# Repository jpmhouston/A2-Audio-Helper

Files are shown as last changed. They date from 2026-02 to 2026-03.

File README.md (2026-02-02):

This is a potential Apple II hardware mod I hope to eventually turn into a working physical add-on for any ][, ][+, //e. It’s meant to add these capabilities:

- route sound card audio to the stock speaker
- mixing motherboard audio into the sound card audio (i believe some sound cards don’t come with this feature)
- an optional second speaker mounted into the case for stereo (mounting strategy not determined yet)
- control volume with a knob protruding through a hole dremel'd into case beneath the keyboard (willing to accept feedback about an alternate volume control and placement, of if volume control should be made optional)
- when volume knob turned off, output to a line-out jack at the back of the case (attached to one of those mounts for a //e, not sure what yet for older ][’s)
- output to headphone jack at the back of the case, also controlled by the volume knob, disabling the speaker(s) when connected (also attached to one of those mounts for a //e, maybe both jacks out one wide slot)
- optionally output to another headphone jack at the front of the case (via a second hole in the case beside the volume knob)

These features should be possible using a small circuit board to be mounted within the case beneath the keyboard with some minor modifications, either one or two holes drilled into the case's metal base, the part that's angled upwards. It should require no controller or firmware, and the plan is to connect it to power and ground via the motherboard’s game port (potentially using a pass-through socket to permit its use for joysticks or whatever else). 

The schematic originates from a specification fed to Gemini and a KiCad project created according to its design, making use of a 8403 amplifier module. Needless to say there were numerous back and forth sessions. I created a simple PCB design as a proof of concept, currently all through-hole components. Well it leverages a ready-to-use amplifier module with its own surface-mount components, but that itself needs connection with pin headers.

The latest iteration of the PCB is 4.5cm wide and 6.3cn tall, and I'm hoping they will fit, on a //e between the motherboard and the end of the flat part of the base, somewhat in the center or right of the case. On a ][ / ][+ I'm hoping there's room in front of the power supply. I know the stock speaker is in that area, I'll have to see more 2's in the wild and see. For both models there should also be space at the far right side of the vents for an second speaker to be mounted somehow.

Volume and front headphone are on a small daughterboard, connected via a ribbon cable, that can mount flush to the upwardly angled part of the base, I'm hoping there's room directly under the keyboard at this angle and still allow the knob and jack to be high enough off the table to be useful. The main board however is also able to have the volume and headphone jack populated on it directly instead, for those wanting to mount it with those controls protruding out the side of the case. I'm making it support this just for me really, as my own case if damaged and I don't mind making holes in the beige plastic, and especially if I run into space issues under the keybaord. I suspect this option will be less of an interest to others since making holes in the beige plastic is not something they'd want to do, and not something I'd recommend.

I also am planning how to mount line-out and optionally a second headphone jack to the back of the case. I've found what might be good jack components, and I think they'll work in one of the long //e openings, but not sure yet. I suspect some 3D-printed thing will be involved in making this work.

I'm putting the cart before the horse a bit iterating over the PCB layout and pondering these physical issues, as I’ve still yet to test an implementation of the schematic on a breadboard.

Feedback and assistance are appreciated on the Discussions page for this repo, especially feedback on the schematic and PCB since I really a beginner in all this. Especially feedback on the physical mounting and modding challenges for this thing. Thanks.

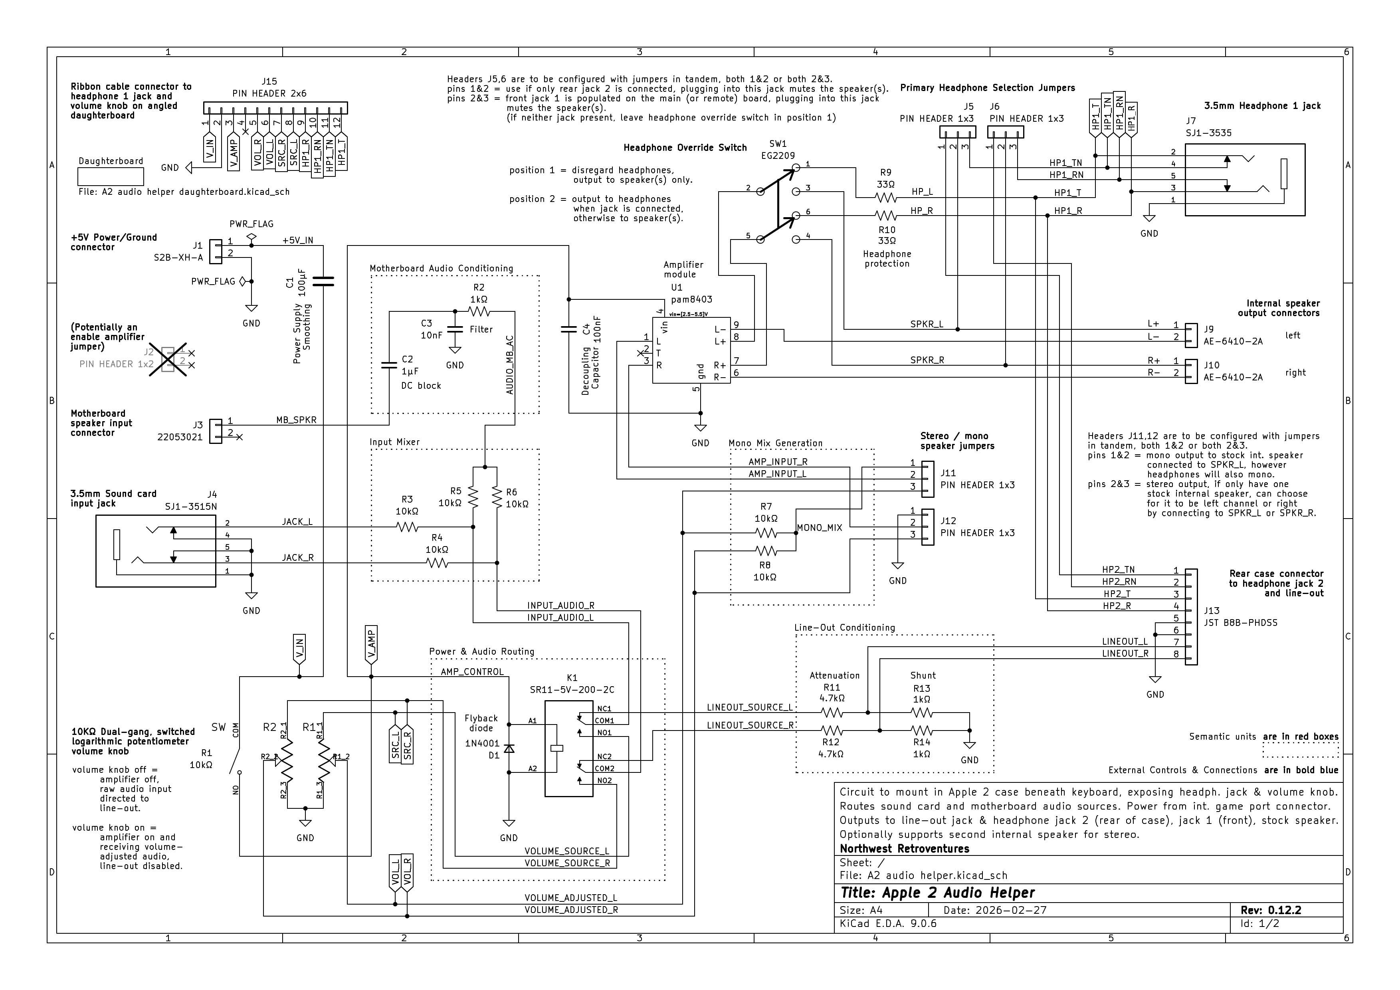
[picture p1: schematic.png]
schematic


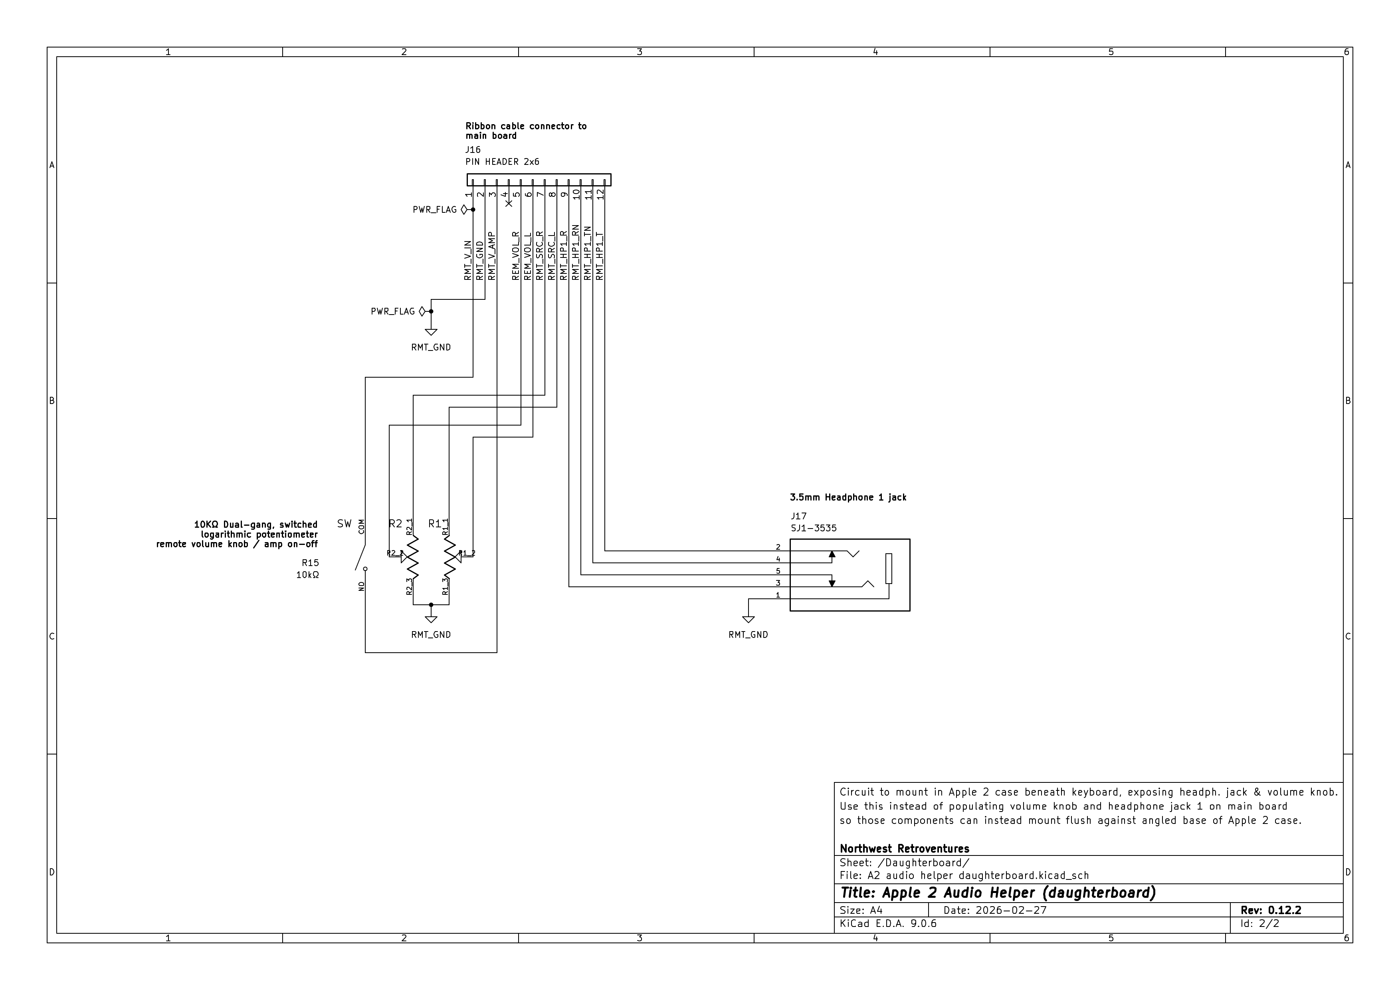
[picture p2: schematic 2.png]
schematic


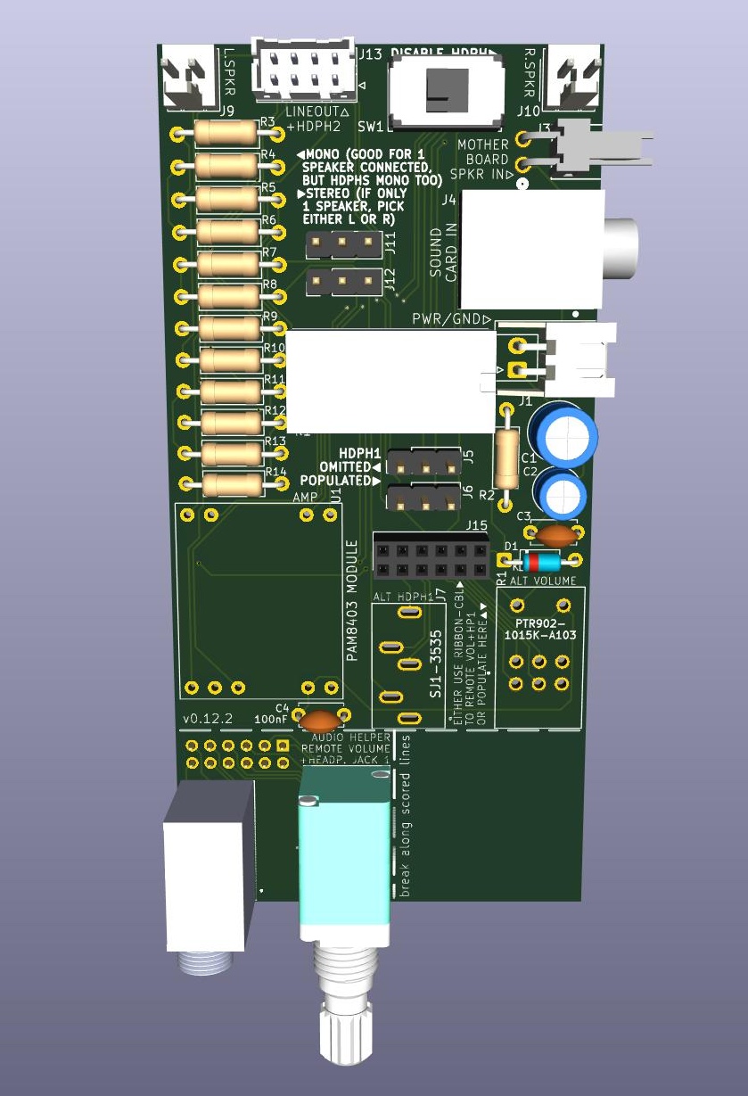
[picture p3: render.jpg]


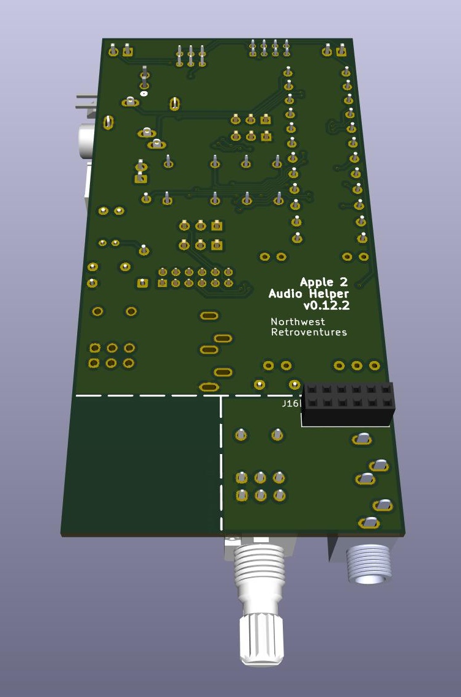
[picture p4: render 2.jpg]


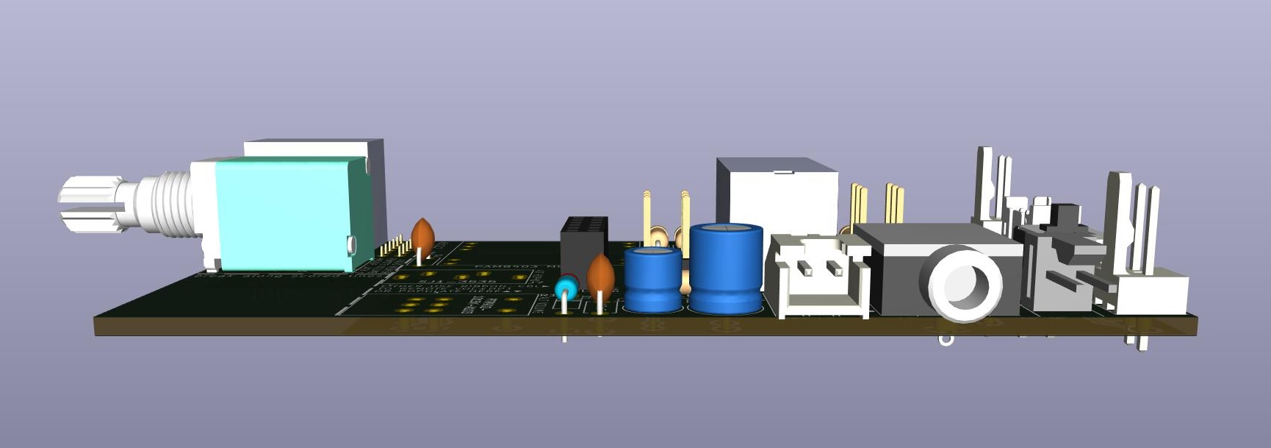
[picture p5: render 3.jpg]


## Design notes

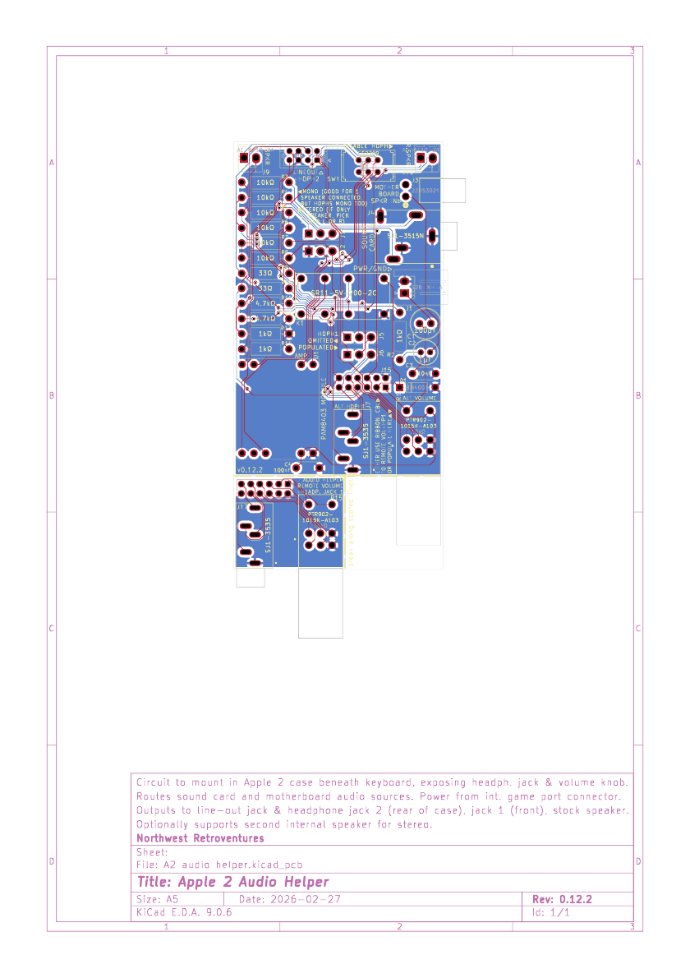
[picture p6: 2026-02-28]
pcb.png

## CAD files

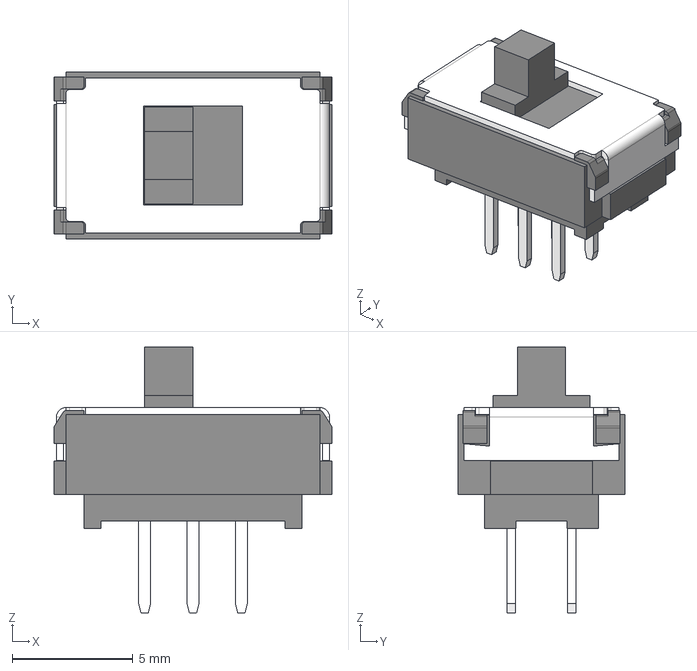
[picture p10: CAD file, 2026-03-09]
EG2209/EG2209.step
11.5 x 6.90 x 11.0 mm

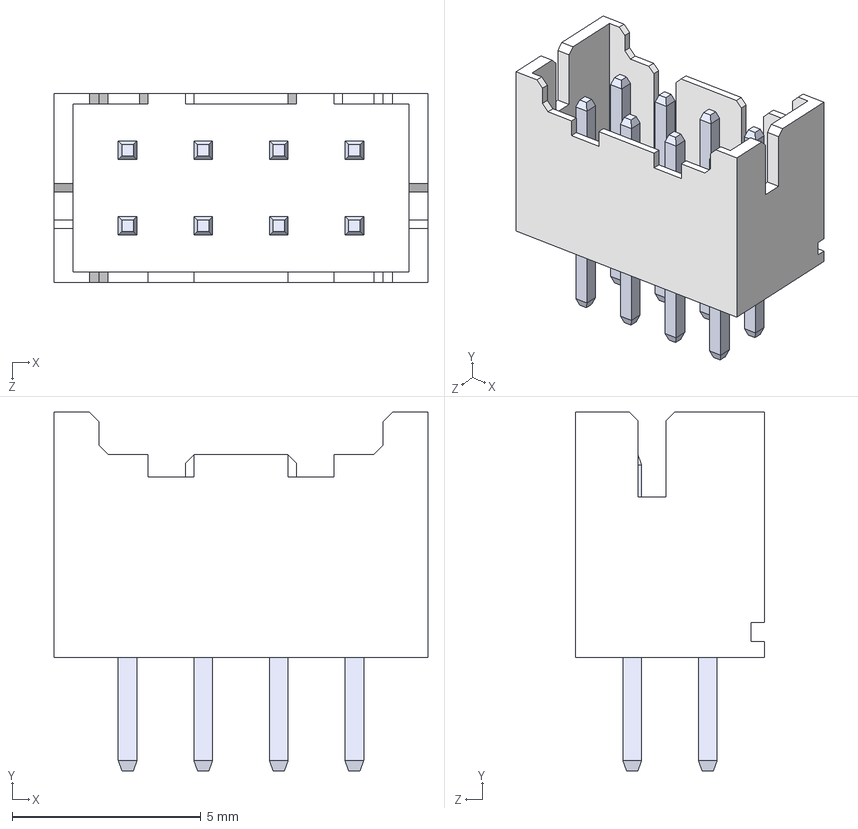
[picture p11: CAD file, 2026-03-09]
JST B8B-PHDSS/B8B-PHDSS -LF--SN---3DModel-STEP-56544.STEP
9.90 x 9.50 x 5.00 mm
BxB-PHDSS_8
pin^BxB-PHDSS ass x 8

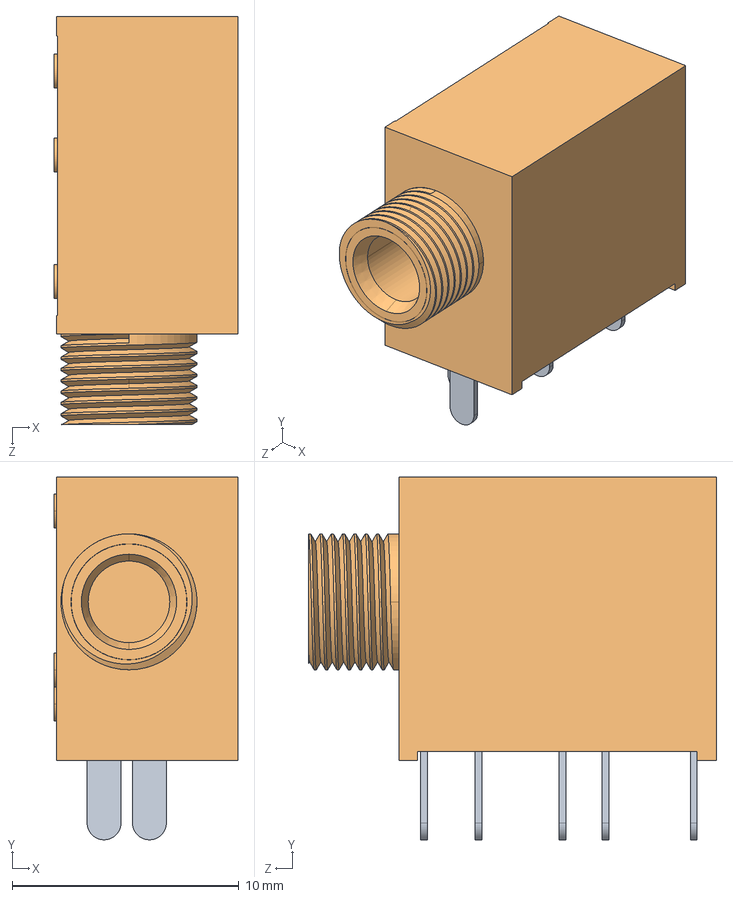
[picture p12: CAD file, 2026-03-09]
SJ1-3535/SJ1-3535.step
8.10 x 16.0 x 18.0 mm

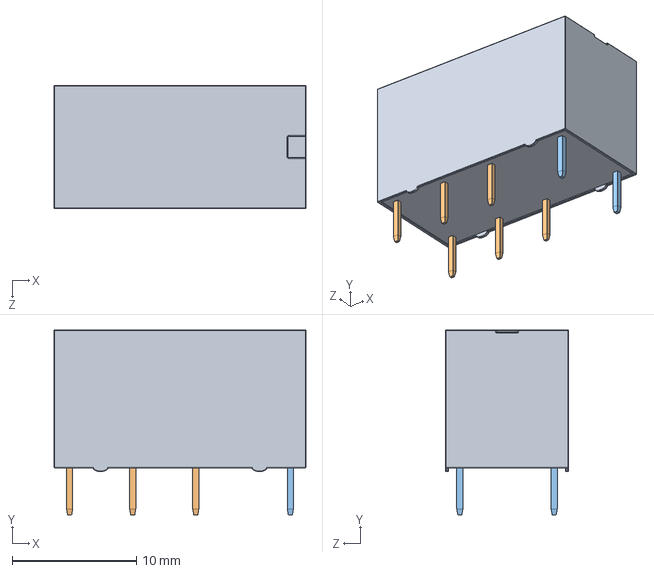
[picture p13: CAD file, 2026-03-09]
SR11-5V-200-2C/SR11-5V-200-2C.step
20.3 x 14.9 x 9.90 mm

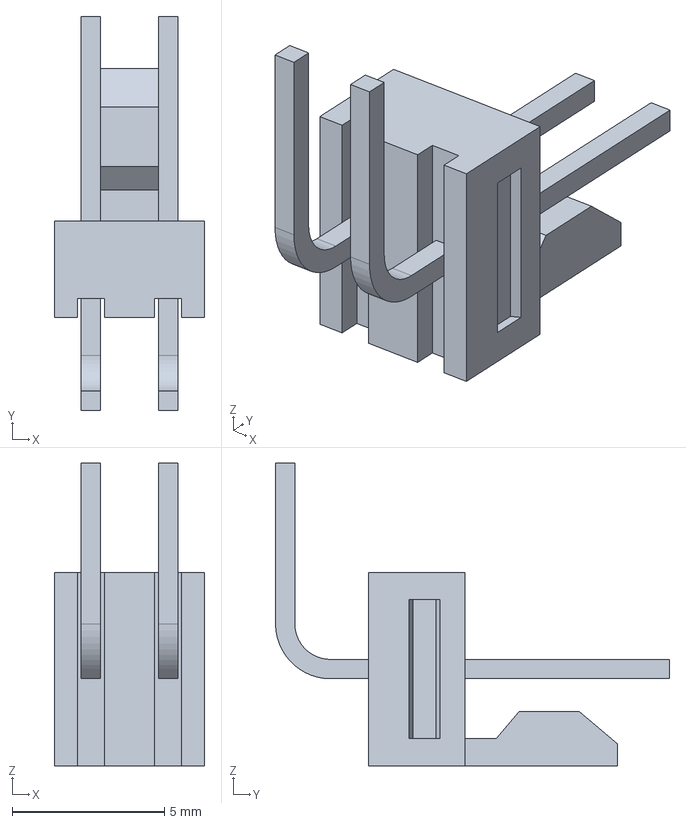
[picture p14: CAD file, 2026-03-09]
Molex 22053021/178334604-659-0022053021/0022053021.stp
4.93 x 12.9 x 9.93 mm

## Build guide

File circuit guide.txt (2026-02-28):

Revision 12 Circuit Design (New headphone 1 jack, switch, layout, remove rev11 experiment)

Libraries, STEP AP242 3D Models for KiCad (add manually, project specific):
* https://github.com/johnnycubides/pam8403-module-kicad-lib (downloaded git repo)
* https://www.snapeda.com/parts/PTR902-1020K-A502/Bourns/view-part/ (symbol file)
* https://www.digikey.com/en/models/24767735 (footprint, 3d model files PTN09S2-H10215K1A analogue to PTR902)
* https://www.snapeda.com/parts/SR11-5V-200-2C/Same%20Sky/view-part/ (symbol, footprint, 3d model files)
* https://www.snapeda.com/parts/SJ1-3515N/Same%20Sky/view-part/ (symbol, footprint, 3d model files)
* https://www.snapeda.com/parts/SJ1-3535/Same%20Sky/view-part/ (symbol, footprint, 3d model files)
* https://www.snapeda.com/parts/EG2209/E-Switch/view-part/ (symbol, footprint, 3d model files)
* https://www.snapeda.com/parts/22053021/Molex/view-part (footprint, 3d model into "Molex 22053021" dir)
* https://www.snapeda.com/parts/B8B-PHDSS%20%28LF%29%28SN%29/JST/view-part/ (3d model into "JST B8B-PHDSS" dir)

--

Component List (Reference Designators)

Main Board

* U1 / U_AMP: PAM8403 Module (Amplifier Module)
* R1 / R_VOL | R_VOL_L, R_VOL_R, SW_R_VOL: 10KΩ Switched Dual-Gang Logarithmic Potentiometer (Volume Knob)
  https://www.snapeda.com/parts/PTR902-1015K-A103/Bourns/view-part/
  footprint PTR902-1020K-A502
  3d model PTR902-1020K-A502/ptr901-2x15k-xxxx.stp
* SW1 / SW_HP_OVERRIDE: DPDT Switch (Headphone Override)
  https://www.snapeda.com/parts/EG2209/E-Switch/view-part/
  footprint EG2209:EG2209
* K1 / RL_AUDIO_RELAY: Relay_DPDT symbol (Mode Relay Routing Audio to Amplifier or Line-Out)
  https://leeselectronic.com/en/product/3219-relayhkehrs2-5vdc-coildpdt1a.html
  https://www.snapeda.com/parts/SR11-5V-200-2C/Same%20Sky/view-part/
  footprint SR11-5V-200-2C:RELAY_SR11-5V-200-2C
  3d model SR11-5V-200-2C/SR11-5V-200-2C.step

* J1 / J_PWR: Conn_01x02 symbol (Main Power Input)
  JST-XH connector more standard than the molex I picked out of a hat, good footprint & model present in kicad
  https://www.snapeda.com/parts/S2B-XH-A/JST%20Sales/view-part
  footprint Connector_JST:JST_XH_S2B-XH-A_1x02_P2.50mm_Horizontal
* J2 / JP_EN_AMP: Conn_01x02 symbol (Jumper to Enable +5V power to U_AMP, omitted from pcb currently)
  footprint PinHeader_1x02_P2.54mm_Vertical
* J3 / J_SPKR_IN: Conn_01x02 symbol (Motherboard Audio Input)
  https://www.snapeda.com/parts/22053021/Molex/view-part/
  footprint Molex 22053021:CONN_A-7478-02A_MOL
  3d model Molex 22053021/178333781-659-0022053021/0022053021.stp
* J4 / J_SCARD_IN: AudioJack3_Ground_Switch symbol (Switching Sound Card Input Jack)
  https://leeselectronic.com/en/product/160956-35mm-stereo-jack-breadboard-friendly.html get this for testing
  https://www.snapeda.com/parts/SJ1-3515N/Same%20Sky/view-part/
  footprint SJ1-3515N:CUI_SJ1-3515N
  3d model SJ1-3515N/SJ1-3515N.step
* J5,6 / JP_SW_PRIM_HP_L, JP_SW_PRIM_HP_R: Two Conn_01x03 symbols (Jumpers for Which Headphone Jack Mutes Speakers)
  footprint PinHeader_1x03_P2.54mm_Vertical
* J7 / J_HP1_OUT: AudioJack3_Ground_Switch symbol (Switching Headphone 1 Jack)
  https://www.snapeda.com/parts/SJ1-3535/Same%20Sky/view-part/
  footprint SJ1-3535:CUI_SJ1-3535
* J8 now unused, was separate connector to hp1 jack
* J9,10 / J_SPKR_OUT_L, J_SPKR_OUT_L: Conn_01x02 symbol (Speaker Output)
  https://www.snapeda.com/parts/22272021/Molex/view-part/
  https://www.molex.com/en-us/products/part-detail/22272021
  footprint Connector_Molex:Molex_KK-254_AE-6410-02A_1x02_P2.54mm_Vertical
* J11,12 / JP_EN_RSPKR_L, JP_EN_RSPKR_R: Two Conn_01x03 symbols (Jumpers for Mono/Stereo Speaker Mode)
  footprint PinHeader_1x03_P2.54mm_Vertical
* J13 / J_REAR_CONN: Conn_01x07 symbol (Connector to Switching Headphone 2 Jack and Line-Out)
  pins are numbered from 1 to 7: HP2_T, HP2_TN, HP2_R, HP2_RN, LINEOUT_L, LINEOUT_R, GND
  JST PHD series, 2.0mm, B8B-PHDSS
  https://www.snapeda.com/parts/B8B-PHDSS(LF)(SN)/JST%20Sales/view-part/
  footprint Connector_JST:JST_PHD_B8B-PHDSS_2x04_P2.00mm_Vertical
  3d model JST B8B-PHDSS/B8B-PHDSS -LF--SN---3DModel-STEP-56544.STEP
* J14 now unused, was separate connector to line-out
* J15 / J_TORMT_RBNCONN: Conn_02x06 symbol (Ribbon cable connector to remote J_RMT_HP1_OUT + R_RMT_VOL)
  footprint Connector_PinSocket_2.00mm:PinSocket_2x06_P2.00mm_Vertical
  https://www.snapeda.com/parts/M22-7140642/Harwin/view-part/
  https://www.snapeda.com/parts/SMM-106-01-S-D/Samtec/view-part/
  2" cable https://www.snapeda.com/parts/TCMD-06-D-02.00-01/Samtec/view-part/

* D1 / D_RELAY_FLYBACK: 1N4148 (or could use 1N4001/1N4007) Diode (Flyback Diode for Mode Relay)
  https://leeselectronic.com/en/product/7113-7113DIODEFASTSWITCHING1N41484PCS.html 
  https://www.snapeda.com/parts/JANTX1N4148-1/Microsemi%20Corporation/view-part/
  footprint Diode_THT:D_DO-35_SOD27_P7.62mm_Horizontal
* C1 / C_PWR_SMOOTH: 100µF Electrolytic Capacitor (Power Supply Smoothing)
  footprint C_Radial_D6.3mm_H7.0mm_P2.50mm
* C2 / C_MB_DC_BLOCK: 1µF Capacitor (Motherboard Audio DC Blocking)
  footprint C_Radial_D5.0mm_H5.0mm_P2.00mm
* C3 / C_MB_FILTER: 10nF Capacitor (Motherboard Audio Filtering)
  footprint C_Disc_D4.7mm_W2.5mm_P5.00mm
* C4 / C_AMP_DECOUPLING: 100nF Capacitor (Amp VCC Decoupling Capacitor)
  footprint Capacitor_THT:C_Disc_D4.7mm_W2.5mm_P5.00mm
* R2 / R_MB_FILTER: 1kΩ Resistor (Motherboard Audio Filtering)
* R3,4 / R_MIX_SCARD_L, R_MIX_SCARD_R: 10kΩ Resistors (Input Mixer for Sound Card Audio)
* R5,6 / R_MIX_MB_L, R_MIX_MB_R: 10kΩ Resistors (Input Mixer for Motherboard Audio)
* R7,8 / R_MONO_MIX_L, R_MONO_MIX_R: 10kΩ Resistors (Output Mono Mix for speakers)
* R9,10 / R_HP_PROT_L, R_HP_PROT_R: 33Ω Resistors (Headphone Protection)
* R11,12 / R_LINE_ATTEN_L, R_LINE_ATTEN_R: 4.7kΩ Resistors (Line-out Attenuation, Series)
* R13,14 / R_SHUNT_L, R_SHUNT_R: 1kΩ Resistors (Line-out Attenuation, Shunt)
  footprint for all restistors R_Axial_DIN0207_L6.3mm_D2.5mm_P10.16mm_Horizontal

Daughterboard

* J16 / J_RMT_RBNCONN: Conn_02x06 symbol (Ribbon cable connector to/at remote J_HP1_OUT + R_VOL)
  footprint Connector_PinSocket_2.00mm:PinSocket_2x06_P2.00mm_Vertical
  https://www.snapeda.com/parts/M22-7140642/Harwin/view-part/
  https://www.snapeda.com/parts/SMM-106-01-S-D/Samtec/view-part/
  2" cable https://www.snapeda.com/parts/TCMD-06-D-02.00-01/Samtec/view-part/
* J17 / J_RMT_HP1_OUT: AudioJack3_Ground_Switch symbol (Switching Headphone 1 Jack)
  https://www.snapeda.com/parts/SJ1-3535/Same%20Sky/view-part/
  footprint SJ1-3535:CUI_SJ1-3535
* R15 / R_RMT_VOL: 10KΩ Switched Dual-Gang Logarithmic Potentiometer (Volume Knob)
  https://www.snapeda.com/parts/PTR902-1015K-A103/Bourns/view-part/
  (model files from the similar 5KΩ part www.snapeda.com/parts/PTR902-1020K-A502/Bourns/view-part/)
  footprint PTR902-1020K-A502
  3d model PTR902-1020K-A502/ptr901-2x15k-xxxx.stp

Also (not on any board or schematic)

* J17 / J_LINEOUT (Rear Case Line-Out Jack)
  Samesky SJ3-35053D 3.5 mm Stereo Jack, Through Hole, 3 Conductors, 2 Internal Switches 
  https://www.sameskydevices.com/product/interconnect/connectors/audio-connectors/jacks/sj3-35053d
* J18 / J_HP2 (Rear Case Headphone 2 Jack)
  Samesky SJ3-35053A 3.5 mm Stereo Jack, Through Hole, 3 Conductors, 0 Internal Switches 
  https://www.sameskydevices.com/product/interconnect/connectors/audio-connectors/jacks/sj3-35053a

Centers of headphone 1 jack and volume knob are 15mm apart, very close to 19/32", ie. 5/8" minus 1/32"
(requires a 0.5mm spacer between board and knob R_VOL)
Holes ~6mm diam. (jack's screw is M6 ie. outer diam. 5.8mm, however knob suggest 6mm is its screw's inner diam)

---

Schematic Description

Block 1: Main Power Input & Amplifier Power Control
* J_PWR (Main Power Header):
    * Pin 1 provides the +5V_IN net.
    * Pin 2 provides the GND net.
* C_PWR_SMOOTH (Power Smoothing Capacitor):
    * Connect the positive lead of C_PWR_SMOOTH to +5V_IN.
    * Connect the negative lead of C_PWR_SMOOTH to GND.
    * Effect: This capacitor acts as a local power reservoir to filter noise and smooth out voltage drops from the Apple II's power supply.
* JP_EN_AMP (Amplifier Enable Jumper):
    * Pin 1 connects to +5V_IN.
    * Pin 2 provides the V_IN_ENABLED net.
    * Effect: When a jumper shunt is present, power is passed to the rest of the circuit.

Block 2: Input Stage & Pre-Mixer
* J_SPKR_IN (Motherboard Audio Header):
    * Pin 1 (MB_SPKR): Connect to C_MB_DC_BLOCK, plug connects to Apple II Speaker Switched Output signal, J18 pin 1 (precise pin needs to be verified).
    * Pin 2: No connection (plug must not connect to J18 pin 2!).
* JP_EN_SPKR_IN (Jumper to Enable MB Audio, currenly omitted but was in between MB_SPKR pin 1 and C_MB_DC_BLOCK):
    * Now unused, but was:
        * Pin 1: Connect to the MB_SPKR signal from J_SPKR_IN.
        * Pin 2: Connect to the MB_SPKR_ENABLED net (ie. to C_MB_DC_BLOCK).
        * Effect: Placing a jumper shunt on JP_EN_SPKR_IN enables the motherboard audio. Removing it disables it.
* Motherboard Audio Conditioning:
    * The MB_SPKR signal goes through series C_MB_DC_BLOCK.
    * Then, it goes through series R_MB_FILTER.
    * A C_MB_FILTER capacitor connects from after R_MB_FILTER to GND. This creates the AUDIO_MB_AC net.
* J_SCARD_IN (Switching Line-In Jack):
    * Tip pin provides the JACK_L net.
    * Ring pin provides the JACK_R net.
    * Sleeve pin connects to GND.
    * The Tip_NC and Ring_NC (Normally Closed) pins connect to GND for noise prevention when no plug is inserted.

Block 3: Mixer
* Input Mixer:
    * AUDIO_MB_AC -> R_MIX_MB_L -> INPUT_AUDIO_L net.
    * AUDIO_MB_AC -> R_MIX_MB_R -> INPUT_AUDIO_R net.
    * JACK_L -> R_MIX_SCARD_L -> INPUT_AUDIO_L net.
    * JACK_R -> R_MIX_SCARD_R -> INPUT_AUDIO_R net.
* Effect: The INPUT_AUDIO_L/R nets now contain a mix of the conditioned motherboard audio (if JP_EN_SPKR_IN is installed) and the line-in signal (if present in J_SCARD_IN).

Block 4: Line-Out / Amp Mode Selection (Volume Knob Switch) & Volume Control
* SW_R_VOL (SPST Switch on R_VOL):
    * Conect one terminal to V_IN_ENABLED.
    * Connect the other terminal to the AMP_CONTROL_SIGNAL net.
* D_RELAY_FLYBACK (Flyback Diode):
    * Cathode (banded end): Connect to AMP_CONTROL_SIGNAL.
    * Anode (non-banded end): Connect to GND.
* RL_AUDIO_RELAY (DPDT Relay) Coil Connections:
    * One side of the relay coil (e.g., A1): Connect to AMP_CONTROL_SIGNAL.
    * The other side of the relay coil (e.g., A2): Connect to GND.
* RL_AUDIO_RELAY (DPDT Relay) Audio Contact Connections:
    * Pole A (Left Channel):
        * Common pin: Connect to INPUT_AUDIO_L.
        * Normally Closed (NC) pin: Connect to LINEOUT_SOURCE_L.
        * Normally Open (NO) pin: Connect to VOLUME_SOURCE_L.
    * Pole B (Right Channel):
        * Common pin: Connect to INPUT_AUDIO_R.
        * Normally Closed (NC) pin: Connect to LINEOUT_SOURCE_R.
        * Normally Open (NO) pin: Connect to VOLUME_SOURCE_R.
* R_VOL_L (Left Gang on R_VOL):
    * Pin 1 (End of Track): Connects to VOLUME_SOURCE_L.
    * Pin 2 (Wiper): Provides the VOLUME_ADJUSTED_L net.
    * Pin 3 (Other End of Track): Connects to GND.
* R_VOL_R (Right Gang on R_VOL):
    * Pin 4 (End of Track): Connects to VOLUME_SOURCE_R.
    * Pin 5 (Wiper): Provides the VOLUME_ADJUSTED_R net.
    * Pin 6 (Other End of Track): Connects to GND.
* Effect:
    * When SW_R_VOL is OFF:
        * The AMP_CONTROL_SIGNAL net and U_AMP are disconnected from V_IN_ENABLED.
        * Audio is routed to LINEOUT_SOURCE_L/R.
    * When SW_R_VOL is ON:
        * The AMP_CONTROL_SIGNAL net and U_AMP are connected to V_IN_ENABLED.
        * Audio is routed to VOLUME_SOURCE_L/R for amplification.

Block 5: Mono Mix Generation & Amplifier Input (Two-Jumper Version)
* Mono Mix Generation: A MONO_MIX_POINT net is created by mixing VOLUME_ADJUSTED_L and VOLUME_ADJUSTED_R through R_MONO_MIX_L and R_MONO_MIX_R.
* JP_EN_RSPKR_L (Left Channel Jumper):
    * Pin 1 (Stereo): Connect to VOLUME_ADJUSTED_L.
    * Pin 2 (Common): Connect to AMP_INPUT_L.
    * Pin 3 (Mono): Connect to MONO_MIX_POINT.
* JP_EN_RSPKR_R (Right Channel Jumper):
    * Pin 1 (Stereo): Connect to VOLUME_ADJUSTED_R.
    * Pin 2 (Common): Connect to AMP_INPUT_R.
    * Pin 3 (Mono): Connect to GND.

Block 6: Amplifier Module
* U_AMP (PAM8403 Module):
    * VCC pin: Connect to AMP_CONTROL_SIGNAL.
    * Ground pin: Connect to GND.
    * L and R input pins: Connect to AMP_INPUT_L and AMP_INPUT_R.
    * L+ and R+ output pins: Connect to the common pins of SW_HP_OVERRIDEA/B.
    * L- and R- output pins: Connect to pin 2 (L-) of J_SPKR_OUT_L and pin 2 (R-) of J_SPKR_OUT_R.

Block 7: Amplified Output Routing
* SW_HP_OVERRIDEA & SW_HP_OVERRIDEB (Headphone Override Switch):
    * The Common pin of SW_HP_OVERRIDEA: Connect to the L+ output of U_AMP.
    * The Common pin of SW_HP_OVERRIDEB: Connect to the R+ output of U_AMP.
    * Throw 2 ("Forced Speaker") of SW_HP_OVERRIDEA: Connect directly to pin 1 (L+) of J_SPKR_OUT_L.
    * Throw 2 ("Forced Speaker") of SW_HP_OVERRIDEB: Connect directly to pin 1 (R+) of J_SPKR_OUT_R.
    * Throw 1 ("Auto") of SW_HP_OVERRIDEA: Connect to the input of the R_HP_PROT_L resistor.
    * Throw 1 ("Auto") of SW_HP_OVERRIDEB: Connect to the input of the R_HP_PROT_R resistor.
* Parallel Audio Path to Headphone Jacks:
    * Output of R_HP_PROT_L: Connect to the HP_L net, connecting in parallel the T (Tip) pin of the J_HP1_OUT jack and pin 1 of J_REAR_CONN (to the T (Tip) pin of the HP2 jack).
    * Output of R_HP_PROT_R: Connect to the HP_R net, connecting in parallel the R (Ring) pin of the J_HP1_OUT jack and pin 3 of J_REAR_CONN (to the R (Ring) pin of the HP2 jack).
    * The signal goes in parallel to the 2 headphones, but when the jumper headers JP_SW_PRIM_HP_L, JP_SW_PRIM_HP_R have pins 1&2 bridged, this will indicate headphone 2 is primary. When pins 2&3 bridged this will indicate headphone 1 is primary. Primary means the headphone that controls muting the speaker(s).
* Headphone Routing:
    * The TN (Tip Normal) pin of J_HP1_OUT: Connect to pin 3 of JP_SW_PRIM_HP_L.
    * The RN (Ring Normal) pin of J_HP1_OUT: Connect to pin 3 of JP_SW_PRIM_HP_R.
    * The S (Sleeve) pin of J_HP1_OUT: Connect to GND.
    * Pin 2 of J_REAR_CONN (to the TN (Tip Normal) pin of the HP2 jack): Connect to pin 1 of JP_SW_PRIM_HP_L.
    * Pin 4 of J_REAR_CONN (to the RN (Ring Normal) pin of the HP2 jack): Connect to pin 1 of JP_SW_PRIM_HP_R.
    * Pin 7 of J_REAR_CONN (to the S (Sleeve) pin of the HP2 jack): Connect to GND.
    * Pin 2 of JP_SW_PRIM_HP_L: Connect to pin 1 (L+) of J_SPKR_OUT_L.
    * Pin 2 of JP_SW_PRIM_HP_R: Connect to pin 1 (R+) of J_SPKR_OUT_R.
* J_SPKR_OUT (Speaker Output Header):
    * L+/R+ pins: Fed by either pins 2 of JP_SW_PRIM_HP_L and JP_SW_PRIM_HP_R, OR from the "Forced Speaker" throws of SW_HP_OVERRIDEA/B.
    * L-/R- pins: Connect directly to the L-/R- outputs of U_AMP.

Block 8: Line-Out Jack
* Line-out signal connects to J_REAR_CONN:
    * LINEOUT_SOURCE_L -> R_LINE_ATTEN_L -> pin 5 of J_REAR_CONN.
    * LINEOUT_SOURCE_R -> R_LINE_ATTEN_R -> pin 6 of J_REAR_CONN.
    * Connect a shunt resistor (R_SHUNT_L/R_SHUNT_R) from each output pin to GND to form the voltage divider.

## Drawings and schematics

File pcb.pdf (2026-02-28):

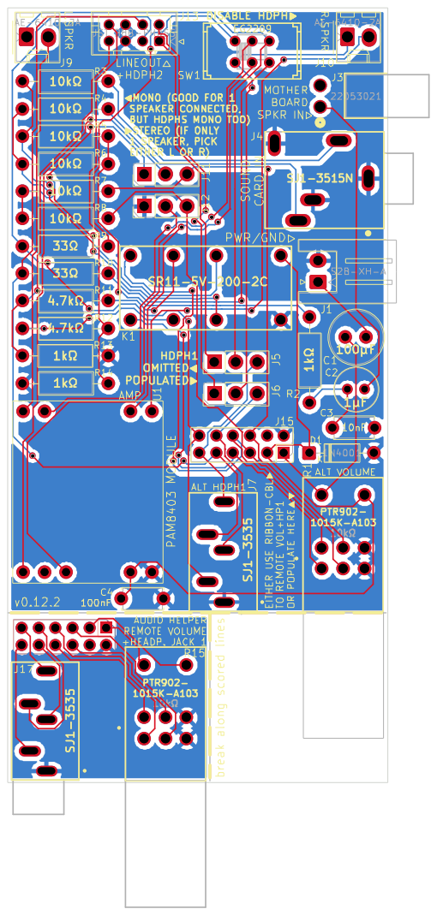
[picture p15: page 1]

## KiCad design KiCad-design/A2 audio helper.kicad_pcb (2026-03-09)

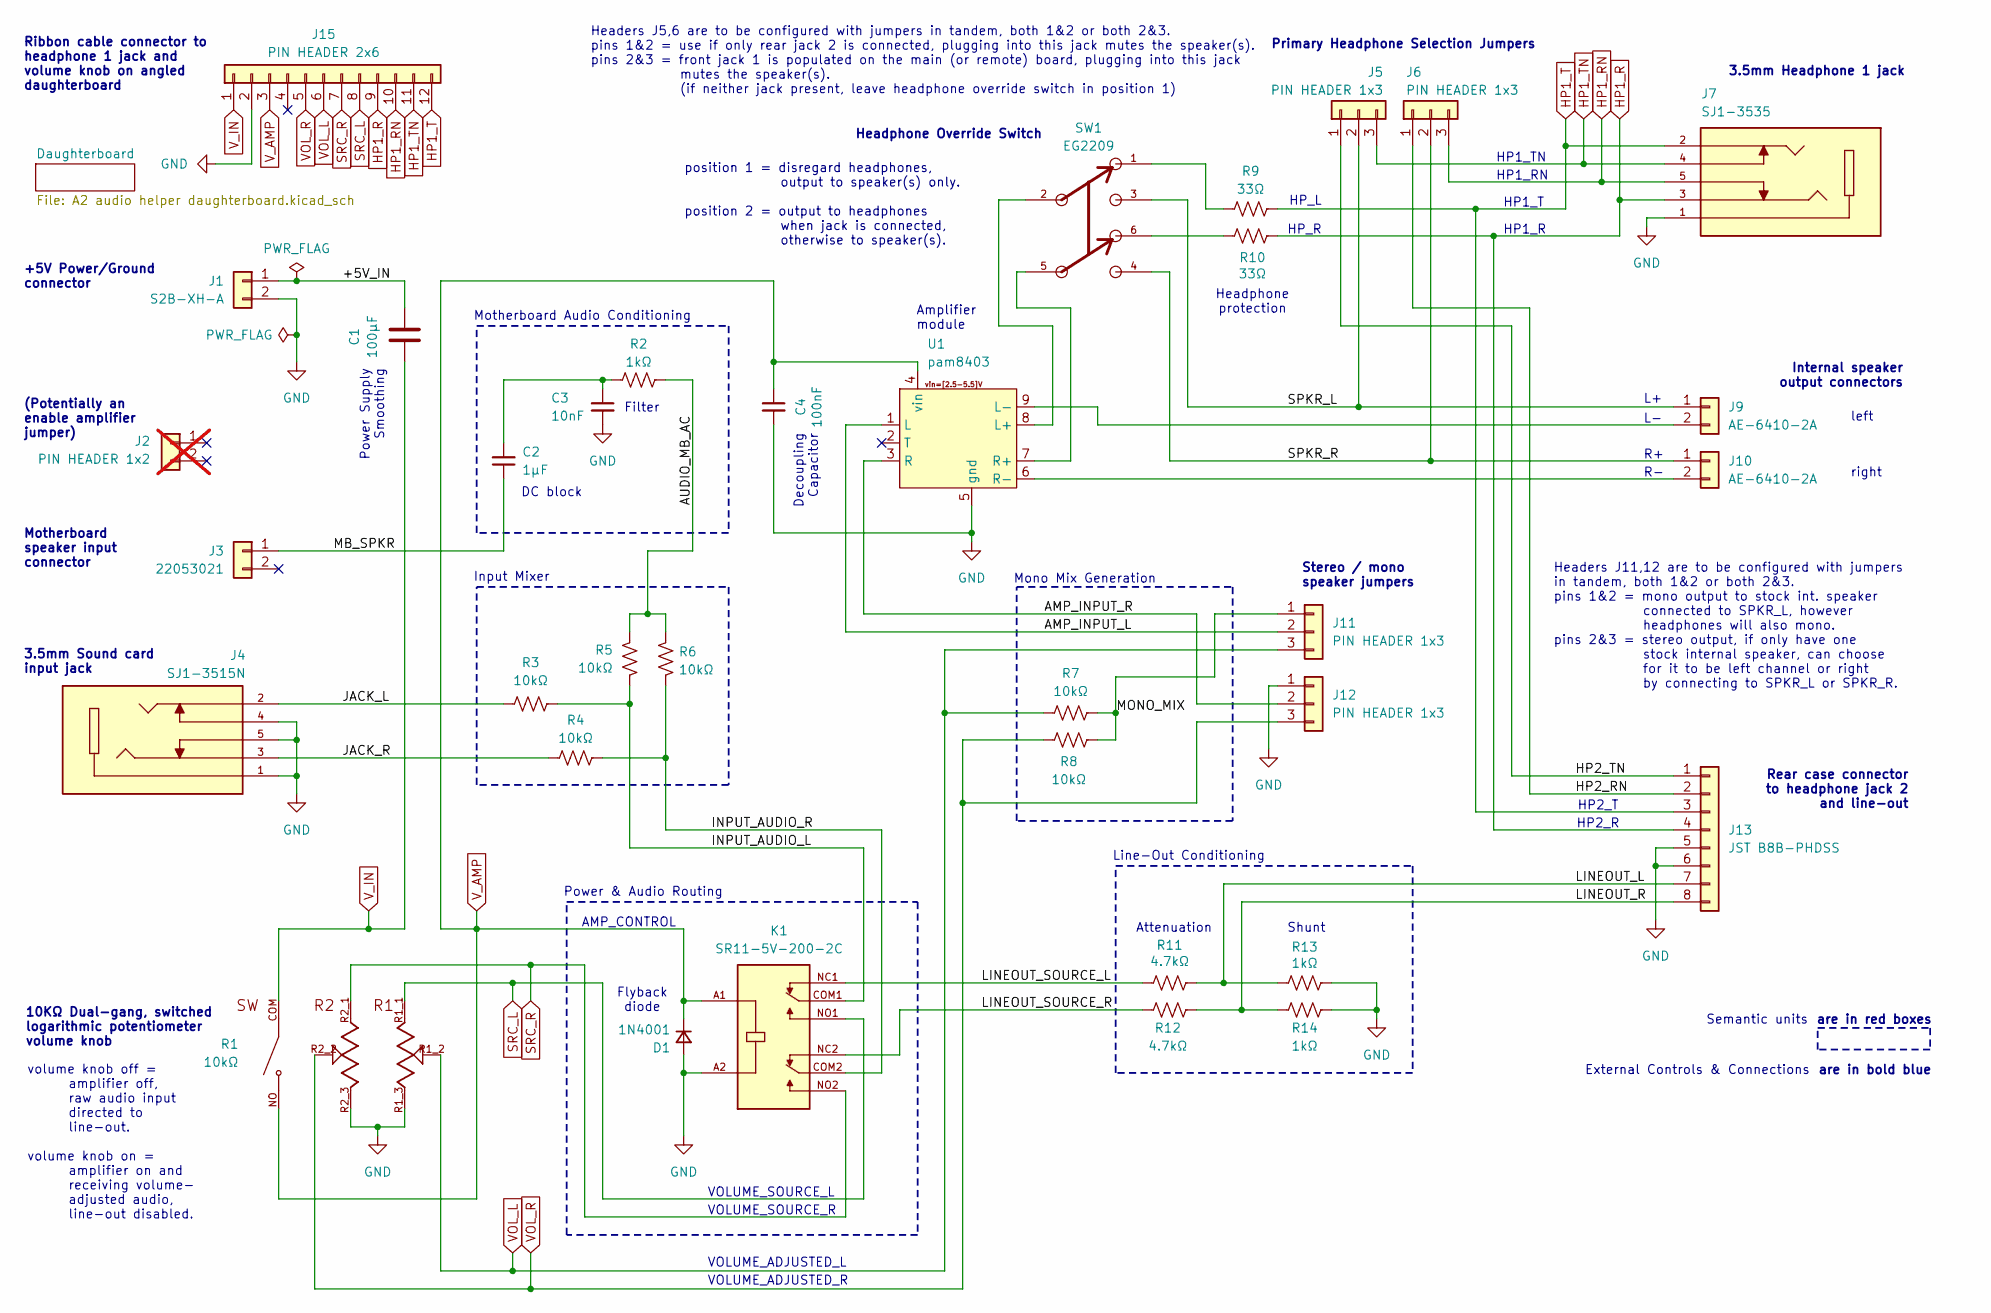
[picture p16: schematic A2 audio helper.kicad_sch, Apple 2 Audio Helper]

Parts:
C1: 100µF; C_Radial_D6.3mm_H7.0mm_P2.50mm
C2: 1µF; C_Radial_D5.0mm_H5.0mm_P2.00mm
C3: 10nF; C_Disc_D4.7mm_W2.5mm_P5.00mm
C4: 100nF; C_Disc_D4.7mm_W2.5mm_P5.00mm
D1: 1N4001; D_DO-35_SOD27_P7.62mm_Horizontal
J1: S2B-XH-A; JST_XH_S2B-XH-A_1x02_P2.50mm_Horizontal
J2: PIN HEADER 1x2; PinHeader_1x02_P2.54mm_Vertical; not fitted
J3: 22053021; CONN_A-7478-02A_MOL
J4: SJ1-3515N; CUI_SJ1-3515N; PARTREV 1.03
J5, J6, J11, J12: PIN HEADER 1x3; PinHeader_1x03_P2.54mm_Vertical
J7: SJ1-3535; CUI_SJ1-3535; PARTREV 1.03
J9, J10: AE-6410-2A; Molex_KK-254_AE-6410-02A_1x02_P2.54mm_Vertical
J13: JST B8B-PHDSS; JST_PHD_B8B-PHDSS_2x04_P2.00mm_Vertical
J15: PIN HEADER 2x6; PinSocket_2x06_P2.00mm_Vertical
K1: SR11-5V-200-2C; RELAY_SR11-5V-200-2C; PARTREV 1.01; DigiKey_Part_Number 2223-SR11-5V-200-2C-ND
R1: 10kΩ; TRIM_PTN09S2-H10215K1A; PARTREV 10/19
R2, R13, R14: 1kΩ; R_Axial_DIN0207_L6.3mm_D2.5mm_P10.16mm_Horizontal
R3, R4, R5, R6, R7, R8: 10kΩ; R_Axial_DIN0207_L6.3mm_D2.5mm_P10.16mm_Horizontal
R9, R10: 33Ω; R_Axial_DIN0207_L6.3mm_D2.5mm_P10.16mm_Horizontal
R11, R12: 4.7kΩ; R_Axial_DIN0207_L6.3mm_D2.5mm_P10.16mm_Horizontal
SW1: EG2209
U1: pam8403

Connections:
/+5V_IN: C1.1, J1.1
/AMP_INPUT_L: J11.2, U1.1 (L)
/AMP_INPUT_R: J12.2, U1.3 (R)
/AUDIO_MB_AC: R2.2, R5.1, R6.1
/HP2_RN: J6.1, J13.2
/HP2_TN: J5.1, J13.1
/INPUT_AUDIO_L: K1.COM1, R3.2, R5.2
/INPUT_AUDIO_R: K1.COM2, R4.2, R6.2
/JACK_L: J4.2, R3.1
/JACK_R: J4.3, R4.1
/LINEOUT_L: J13.7, R11.2, R13.1
/LINEOUT_R: J13.8, R12.1, R14.1
/LINEOUT_SOURCE_L: K1.NC1, R11.1
/LINEOUT_SOURCE_R: K1.NC2, R12.2
/MB_SPKR: C2.1, J3.1
/MONO_MIX: J11.1, R7.2, R8.2
/SPKR_L: J5.2, J9.1, SW1.3
/SPKR_R: J6.2, J10.1, SW1.4
GND: C3.2, C4.2, D1.2 (A), J1.2, J4.1, J4.4, J4.5, J7.1, J12.1, J13.5, J13.6, J15.2, K1.A2, R1.R1_3, R1.R2_3, R13.2, R14.2, U1.5 (gnd)
HP1_R: J7.3, J13.4, J15.9, R10.2
HP1_RN: J6.3, J7.5, J15.10
HP1_T: J7.2, J13.3, J15.12, R9.2
HP1_TN: J5.3, J7.4, J15.11
unnamed: C2.2, C3.1, R2.1
unnamed: J9.2, U1.9 (L-)
unnamed: J10.2, U1.6 (R-)
unnamed: R9.1, SW1.1
unnamed: R10.1, SW1.6
unnamed: SW1.2, U1.8 (L+)
unnamed: SW1.5, U1.7 (R+)
SRC_L: J15.8, K1.NO1, R1.R1_1
SRC_R: J15.7, K1.NO2, R1.R2_1
VOL_L: J11.3, J15.6, R1.R1_2, R7.1
VOL_R: J12.3, J15.5, R1.R2_2, R8.1
V_AMP: C4.1, D1.1 (K), J15.3, K1.A1, R1.NO, U1.4 (vin)
V_IN: C1.2, J15.1, R1.COM

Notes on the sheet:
VOLUME_ADJUSTED_R
Headphone Override Switch
3.5mm Sound card input jack
HP2_R
10KΩ Dual-gang, switched logarithmic potentiometer volume knob
Motherboard speaker input connector
HP1_TN
Mono Mix Generation
HP2_T
are in red boxes
AMP_CONTROL
Ribbon cable connector to headphone 1 jack and volume knob on angled daughterboard
Primary Headphone Selection Jumpers
HP1_T
External Controls & Connections
HP_L
Headphone protection
Headers J5,6 are to be configured with jumpers in tandem, both 1&2 or both 2&3. pins 1&2 = use if only rear jack 2 is connected, plugging into this jack mutes the speaker(s). pins 2&3 = front jack 1 is populated on the main (or remote) board, plugging into this jack mutes the speaker(s). (if neithe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
HP1_R
Semantic units
Stereo / mono speaker jumpers
Motherboard Audio Conditioning
DC block
volume knob off = amplifier off, raw audio input directed to line-out. volume knob on = amplifier on and receiving volume- adjusted audio, line-out disabled.
Attenuation
Decoupling Capacitor
Input Mixer
(Potentially an enable amplifier jumper)
VOLUME_SOURCE_R
Rear case connector to headphone jack 2 and line-out
Flyback diode
HP1_RN
position 1 = disregard headphones, output to speaker(s) only. position 2 = output to headphones when jack is connected, otherwise to speaker(s).
VOLUME_ADJUSTED_L
left
HP_R
Shunt
are in bold blue
Filter
Power Supply Smoothing

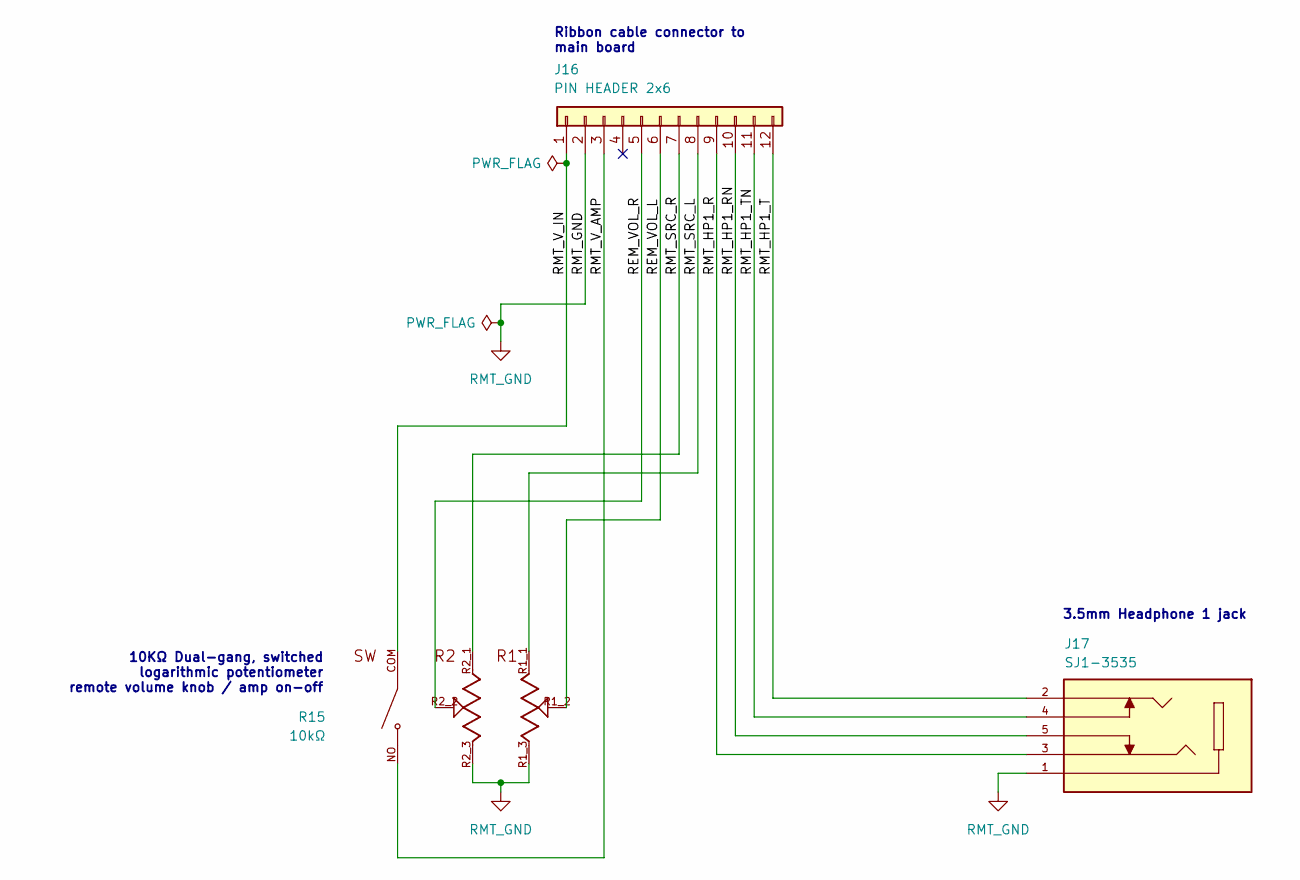
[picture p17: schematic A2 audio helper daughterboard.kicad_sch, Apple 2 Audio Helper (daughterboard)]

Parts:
J16: PIN HEADER 2x6; PinSocket_2x06_P2.00mm_Vertical
J17: SJ1-3535; CUI_SJ1-3535; PARTREV 1.03
R15: 10kΩ; TRIM_PTN09S2-H10215K1A; PARTREV 10/19

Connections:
/Daughterboard/REM_VOL_L: J16.6, R15.R1_2
/Daughterboard/REM_VOL_R: J16.5, R15.R2_2
/Daughterboard/RMT_HP1_R: J16.9, J17.3
/Daughterboard/RMT_HP1_RN: J16.10, J17.5
/Daughterboard/RMT_HP1_T: J16.12, J17.2
/Daughterboard/RMT_HP1_TN: J16.11, J17.4
/Daughterboard/RMT_SRC_L: J16.8, R15.R1_1
/Daughterboard/RMT_SRC_R: J16.7, R15.R2_1
/Daughterboard/RMT_V_AMP: J16.3, R15.NO
/Daughterboard/RMT_V_IN: J16.1, R15.COM
RMT_GND: J16.2, J17.1, R15.R1_3, R15.R2_3

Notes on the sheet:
10KΩ Dual-gang, switched logarithmic potentiometer remote volume knob / amp on-off
Ribbon cable connector to main board
3.5mm Headphone 1 jack

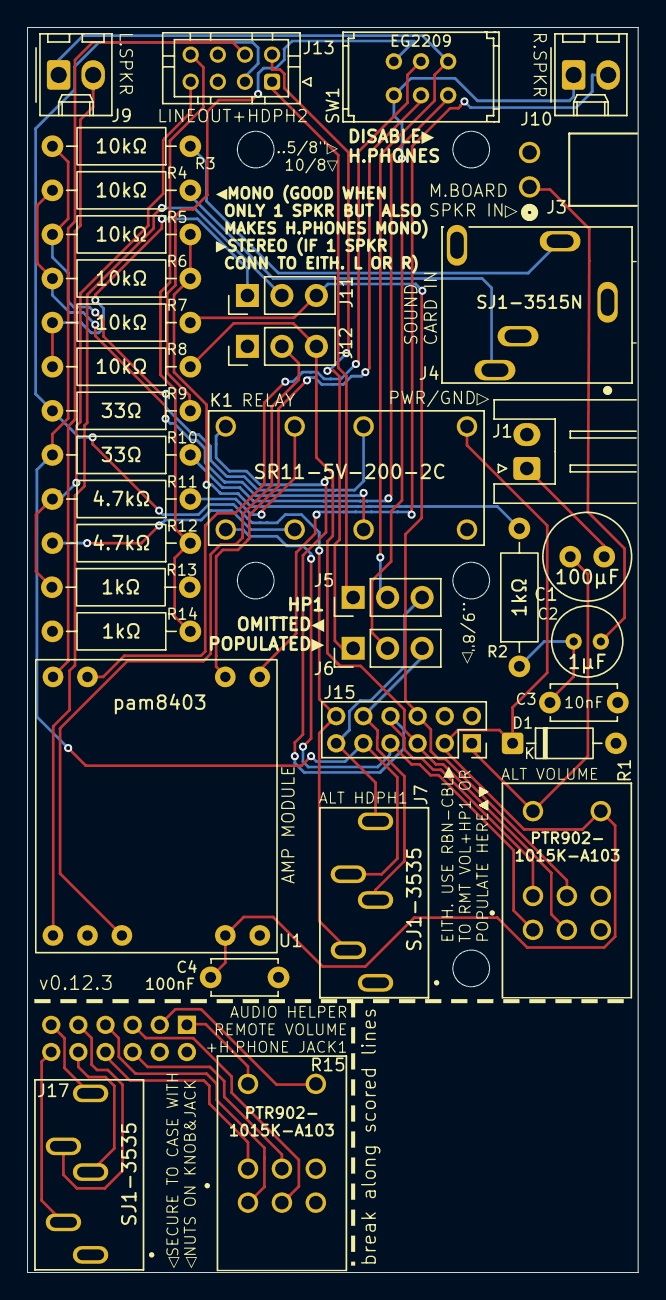
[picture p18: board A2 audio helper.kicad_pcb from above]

Board: 2 copper layers, 45.0 x 91.8 mm, 37 parts (1 on the bottom side), 47 nets.

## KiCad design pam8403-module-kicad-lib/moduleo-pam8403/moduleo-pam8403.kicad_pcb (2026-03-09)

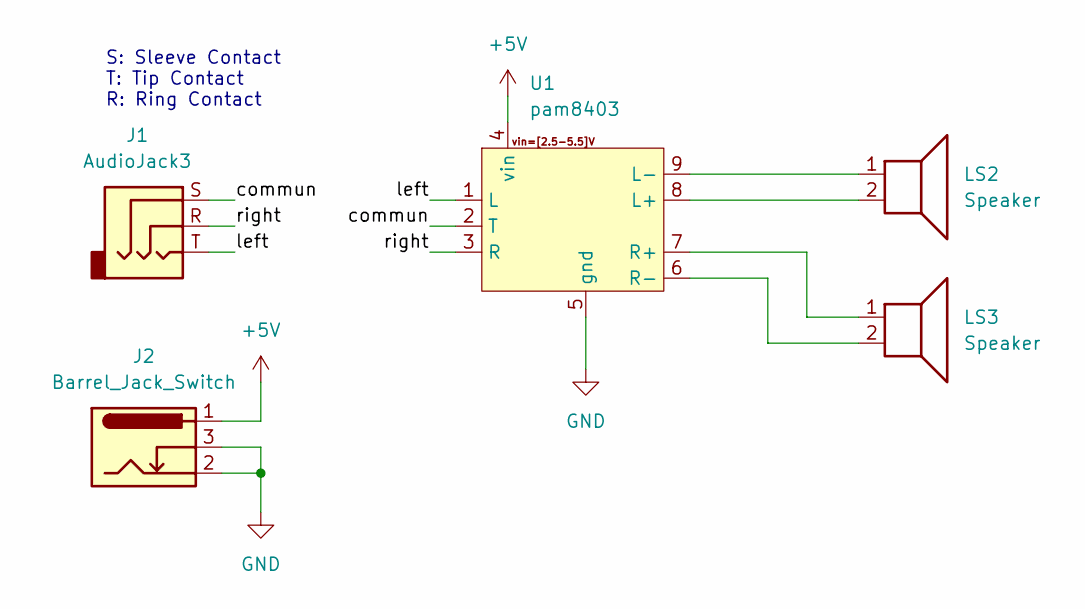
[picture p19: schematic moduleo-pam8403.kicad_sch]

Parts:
J1: AudioJack3; Jack_3.5mm_CUI_SJ1-3533NG_Horizontal_CircularHoles
J2: Barrel_Jack_Switch; BarrelJack_Horizontal
LS2, LS3: Speaker; Molex_KK-396_A-41792-0002_1x02_P3.96mm_Horizontal
U1: pam8403

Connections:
+5V: J2.1, U1.4 (vin)
/commun: J1.S, U1.2 (T)
/left: J1.T, U1.1 (L)
/right: J1.R, U1.3 (R)
GND: J2.2, J2.3, U1.5 (gnd)
unnamed: LS3.2, U1.6 (R-)
unnamed: LS3.1, U1.7 (R+)
unnamed: LS2.2, U1.8 (L+)
unnamed: LS2.1, U1.9 (L-)

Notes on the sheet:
S: Sleeve Contact T: Tip Contact R: Ring Contact

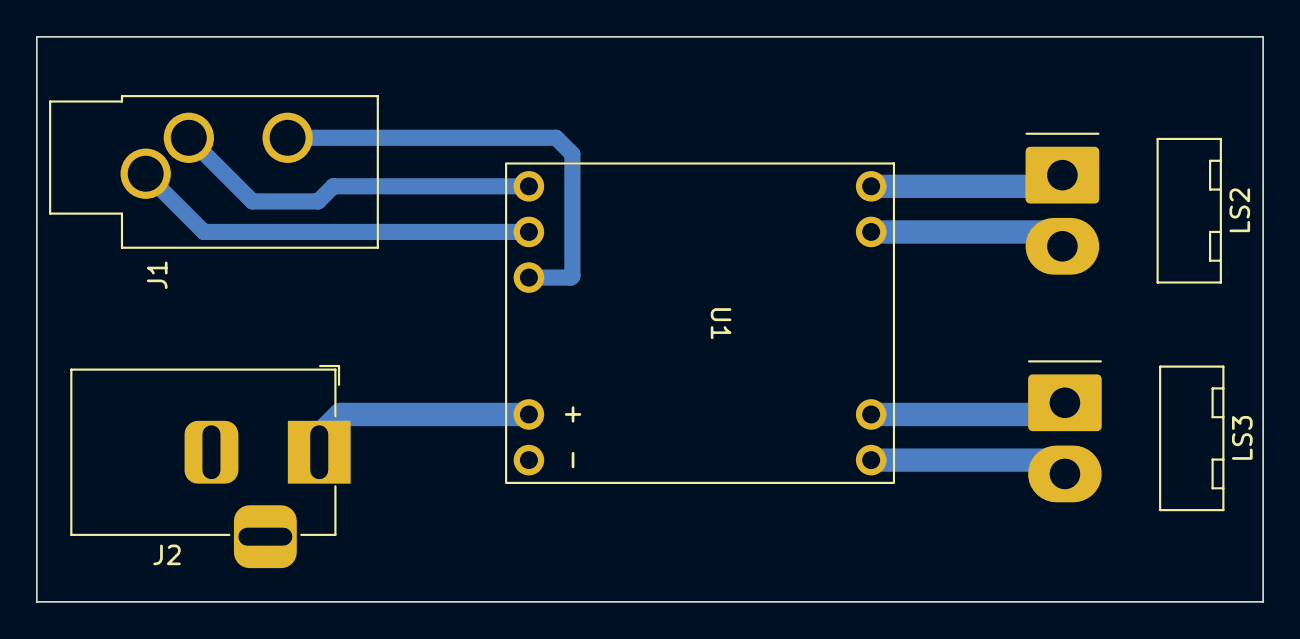
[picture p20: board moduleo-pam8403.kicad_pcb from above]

Board: 2 copper layers, 68.3 x 31.5 mm, 5 parts (0 on the bottom side), 9 nets.

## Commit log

2026-01-06 add kicad proj with rev 1 of the schematic
    [A2 audio helper 2.kicad_pcb, A2 audio helper 2.kicad_sch]
2026-01-09 add guide textfile, revise sc. for simulation WIP
    [A2 audio helper 2.kicad_sch]
2026-01-10 rename circuit guide, stripping adhoc versioning within its filename
2026-01-10 revision 4 of the guide & schematic
    [A2 audio helper 2.kicad_sch]
2026-01-10 fixed schematic mistakes & warnings
    [A2 audio helper 2.kicad_sch]
2026-01-11 fixed schematic issues from sim attempts, better layout
    [A2 audio helper 2.kicad_sch]
2026-01-12 added 5V smoothing cap, added rear hp jack connector
    [A2 audio helper 2.kicad_sch]
2026-01-17 syms/footprints, 1st draft pcb
    [A2 audio helper 2.kicad_pcb, A2 audio helper 2.kicad_sch]
2026-01-18 minor simplification, 1st draft pcb
    [A2 audio helper 2.kicad_pcb, A2 audio helper 2.kicad_sch]
2026-01-20 picked new connectors, pcb take 2
    [A2 audio helper 2.kicad_pcb, A2 audio helper 2.kicad_sch]
2026-01-20 ribbon cbl to remote vol & headph board
    [A2 audio helper 2.kicad_pcb, A2 audio helper 2.kicad_sch]
2026-01-20 ribbon cable part link in guide
2026-01-21 desc'd ribbon conn better in schematic, fixed LSPKR+ error
    [A2 audio helper 2.kicad_pcb, A2 audio helper 2.kicad_sch]
2026-01-25 daughtercard pcb, for now connected & perforated
    [A2 audio helper 2 daughterboard.kicad_sch, A2 audio helper 2.kicad_pcb, A2 audio helper 2.kicad_sch]
2026-01-29 fixed dual headphones
    [A2 audio helper 2.kicad_pcb, A2 audio helper daughterboard.kicad_sch, A2 audio helper.kicad_pcb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]
2026-01-30 improved fix for dual headphones
    [A2 audio helper.kicad_pcb, A2 audio helper.kicad_sch]
2026-02-01 tweaks to pcb, found vol knob 3dmodel
    [A2 audio helper.kicad_pcb]
2026-02-02 combined connector to back of case, lineout & hdph 2
2026-02-07 made power & speaker input connectors also horizontal
    [A2 audio helper daughterboard.kicad_sch, A2 audio helper.kicad_pcb, A2 audio helper.kicad_sch]
2026-02-09 added recommended decoupling cap to amp pwr/gnd
    [A2 audio helper daughterboard.kicad_sch, A2 audio helper.kicad_pcb, A2 audio helper.kicad_sch]
2026-02-19 changed pwr/gnd connector to more common jst connector
    [A2 audio helper.kicad_pcb, A2 audio helper.kicad_sch]
2026-02-19 fixed mb spkr pin 2 which isnt ground afterall
    [A2 audio helper daughterboard.kicad_sch, A2 audio helper.kicad_pcb, A2 audio helper.kicad_sch]
2026-02-21 trim some footprints to edges, pos'n consistently
    [A2 audio helper.kicad_pcb]
2026-02-26 change 3d model for vol knob
    [A2 audio helper daughterboard.kicad_sch, A2 audio helper.kicad_pcb, A2 audio helper.kicad_sch]
2026-02-27 picked new part for front hp jack
    [A2 audio helper daughterboard.kicad_sch, A2 audio helper.kicad_pcb, A2 audio helper.kicad_sch]
2026-02-28 lengthened, new bigger switch part, cleanup
    [A2 audio helper daughterboard.kicad_sch, A2 audio helper.kicad_pcb, A2 audio helper.kicad_sch]
2026-03-09 pcb mount holes, add missing component files
    [0022053021.stp, A2 audio helper.kicad_pcb, B8B-PHDSS -LF--SN---3DModel-STEP-56544.STEP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]
